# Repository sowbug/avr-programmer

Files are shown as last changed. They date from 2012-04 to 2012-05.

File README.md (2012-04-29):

AVR In-System Programmer
========================

By [Mike Tsao](http://www.sowbug.com/) and [Dennis Gentry](https://github.com/dgentry)

Introduction
============

This is a new spin on the AVR ISP. It's based on the ATmega 'u2 family of AVR devices. Influences while designing, in no particular order:

  * Adafruit's [USBtinyISP](http://www.ladyada.net/make/usbtinyisp/), based on [the original USBtiny project](http://dicks.home.xs4all.nl/avr/usbtiny/). In particular, the buffer came from this project.
  * Fabio Baltieri's [USB Key AVR Programmer](http://fabiobaltieri.com/2011/09/02/usb-key-avr-programmer/). Some early schematic ideas came from here.
  * [Saleae Logic](http://www.saleae.com/logic). Yes, I know that's not an AVR programmer, but I like their design sensibilities.
  * [Frank Zhao](http://frank-zhao.com/) provided feedback on an early version of the circuit.

Design Goals
============

  1. It should be pocketable, or capable of being kept in a mesh backpack compartment, without snagging on anything. This means SMD rather than through-hole, few or no required pin headers, and right-angle headers where headers are required.
  1. No special cables needed. In the common case of a standard 6-pin ISP header on the target board, the programmer needs only a commodity mini-B USB cable. The target audience is DIY people who are designing their own circuits, and in that case it's very unlikely new designs would use a 10-pin ISP header with 4 NC pins.
  1. It should be a real USB device rather than emulating serial over USB, so it needs fewer avrdude options to pass in.
  1. Jumpers should be truly optional. The device should be usable without jumper header pins even soldered onto the board.
  1. Support in current versions of avrdude. With the real-USB-device requirement, this narrows it down to USBasp, USBtiny, or AVRISP mkII emulation.
  1. Inexpensive. To be clear, most AVR programmers are inexpensive, and it's not a goal to be less expensive than them.
  1. Distinctive. The angled 6-pin socket satisfies this goal.
  1. Fast. This should be entirely dependent on the quality of the firmware, because the device itself should be capable of high-speed USB.
  1. Good-looking enough to be presentable without a case.
  1. JTAG/XSVF programming via [The JTAG Whisperer](https://github.com/sowbug/JTAGWhisperer). This means we need to support varying target voltages.
  1. Bring out the serial pins on the ATmega to provide a USB-to-TTL converter with an FTDI-cable-compatible pinout.
  1. Support for all low-voltage programming methods (SPI, TPI, PDI). Note that TPI/PDI turned out to be hard to do with the serial functionality. It should work, but with external resistors and a breadboard.

Notes That Will Someday Become Documentation
============================================

* Fuses are **-U lfuse:w:0xDE:m -U hfuse:w:0xD9:m -U efuse:w:0xF7:m -U lock:w:0xFF:m**. These are default with 16MHz crystal and HWBE=0.

FAQ
===

  * **Err, USBasp? USBtiny? You know those bitbang USB, right? Why consider those protocols if your ATmegaXXu2 has native USB?** It's just a question of avrdude support. Both those protocols are based on open-source hardware, so I'd prefer to base my work on them. Another consideration is that there shouldn't be a problem with borrowing their VID/PID pairs. The bit-banging aspect of the protocols is orthogonal to their suitability.
  * **Your circuit mentions the ATmega8u2. You know the '32u2 is only like $1.00 more, right?** True (actually only 40 cents more in quantity), and the initial prototypes will use the '32u2. But we're going to try to fit the intended functionality into 8KB flash and 512 bytes SRAM. Beyond that, the device is looking more like a general-purpose gadget. If we were building such a thing, the ATmega32u4 (not the 32u2) is a better choice.
  * **About that general-purpose gadget: why aren't you building one? The [Bus Pirate](http://dangerousprototypes.com/docs/Bus_Pirate) is cool.** Yes, the Bus Pirate is cool, and indeed it would be nice to have one built on an open toolchain. But this isn't that device. The intent is to have a specialized tool that's always available, never needing a misplaced cable, never needing a firmware update, during those times when you've bricked an AVR or CPLD and just need it fixed.
  * **What's this about AVRISP mkII?** Right, at the moment the prototypes are running the [LUFA project AVRISP mkII](http://www.fourwalledcubicle.com/AVRISP.php). This hardware doesn't include any of its own software, but just in case you build a copy and run LUFA on it, we'd like to incorporate [LUFA's MIT-style license](https://github.com/sowbug/lufa-lib/blob/master/trunk/LUFA/License.txt) and [copyright notice](https://github.com/sowbug/lufa-lib/blob/master/trunk/LUFA/Version.h) by reference here. Thanks, Dean!

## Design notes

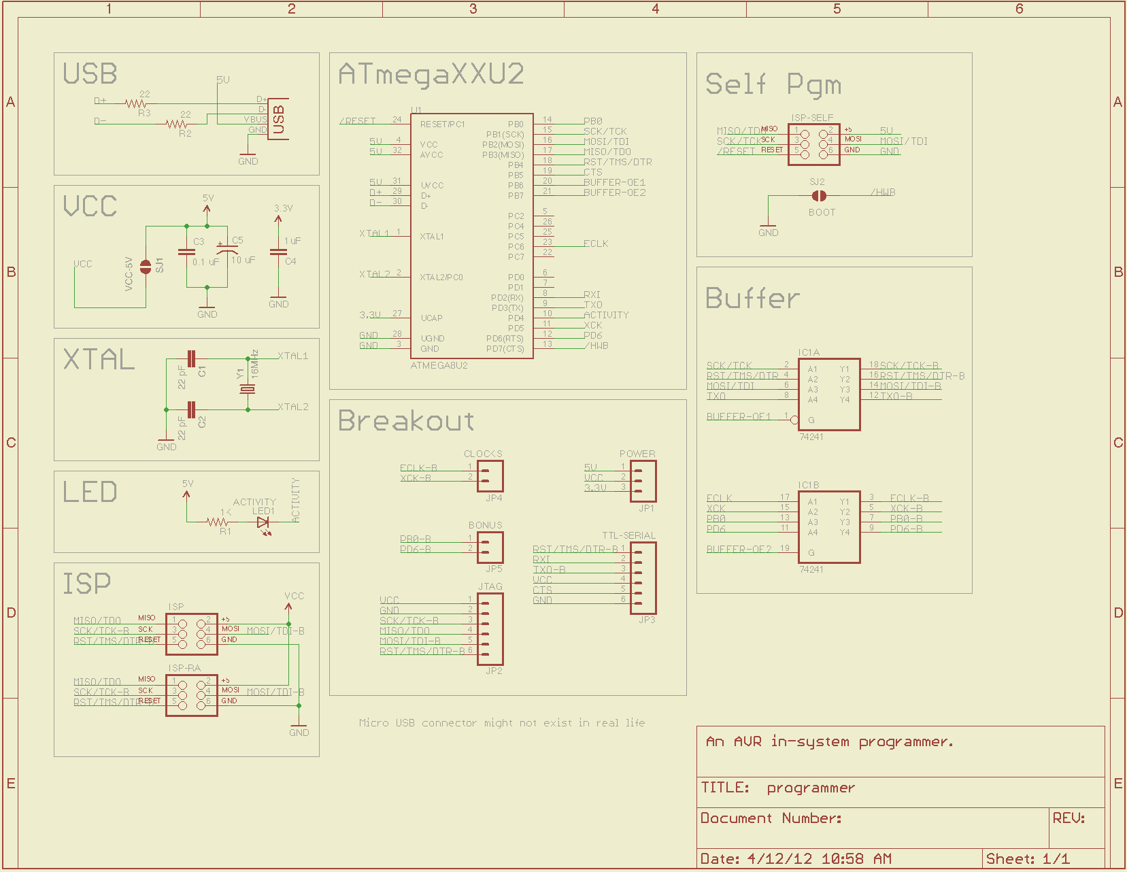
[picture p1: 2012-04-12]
programmer.sch.png

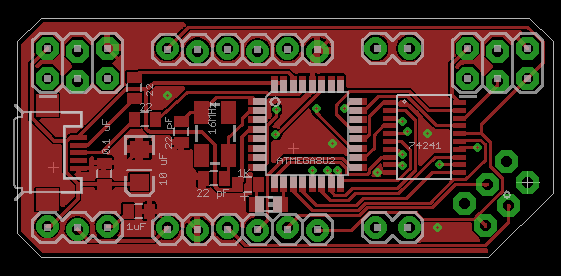
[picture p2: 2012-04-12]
programmer.brd.png

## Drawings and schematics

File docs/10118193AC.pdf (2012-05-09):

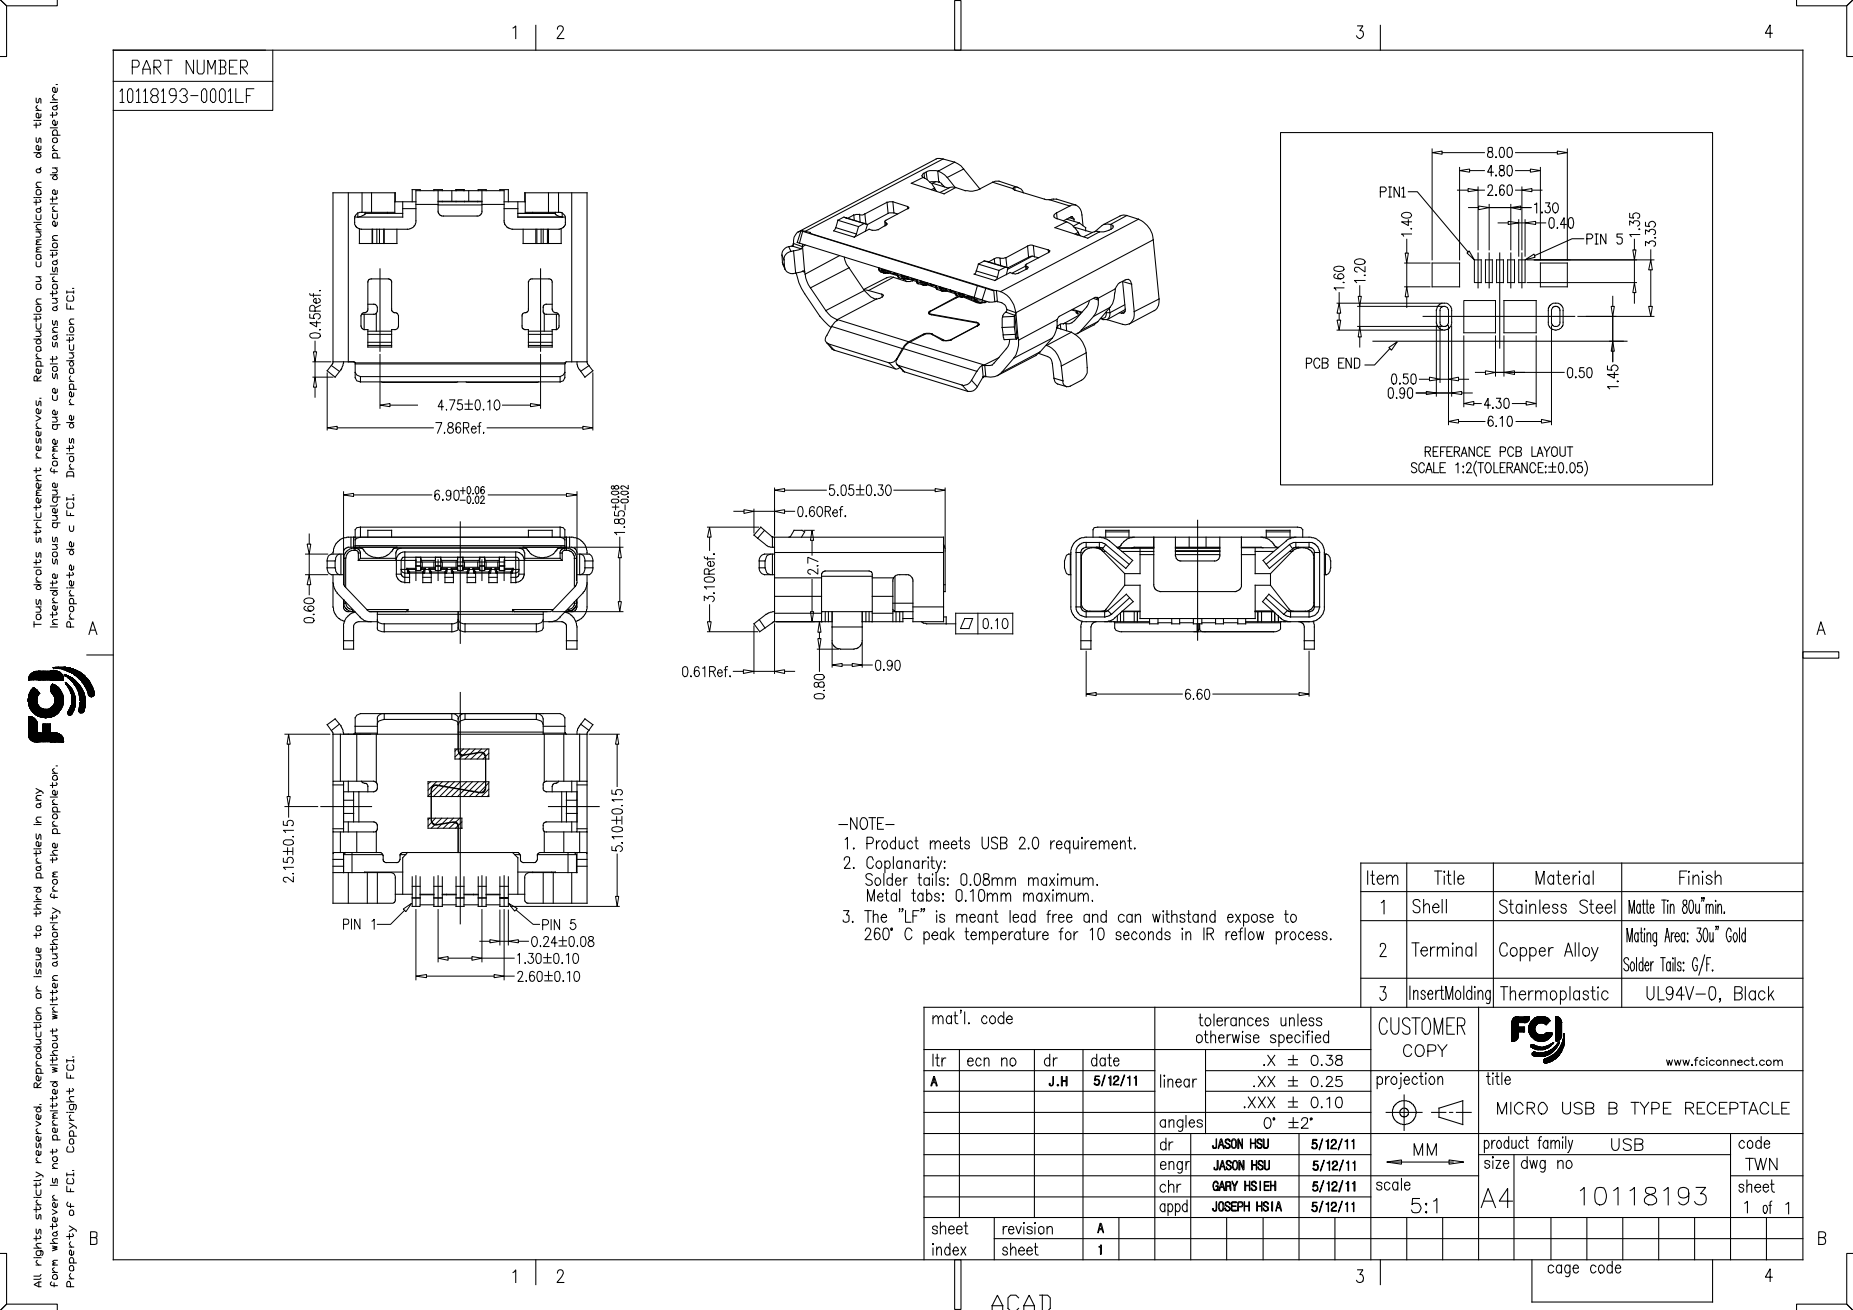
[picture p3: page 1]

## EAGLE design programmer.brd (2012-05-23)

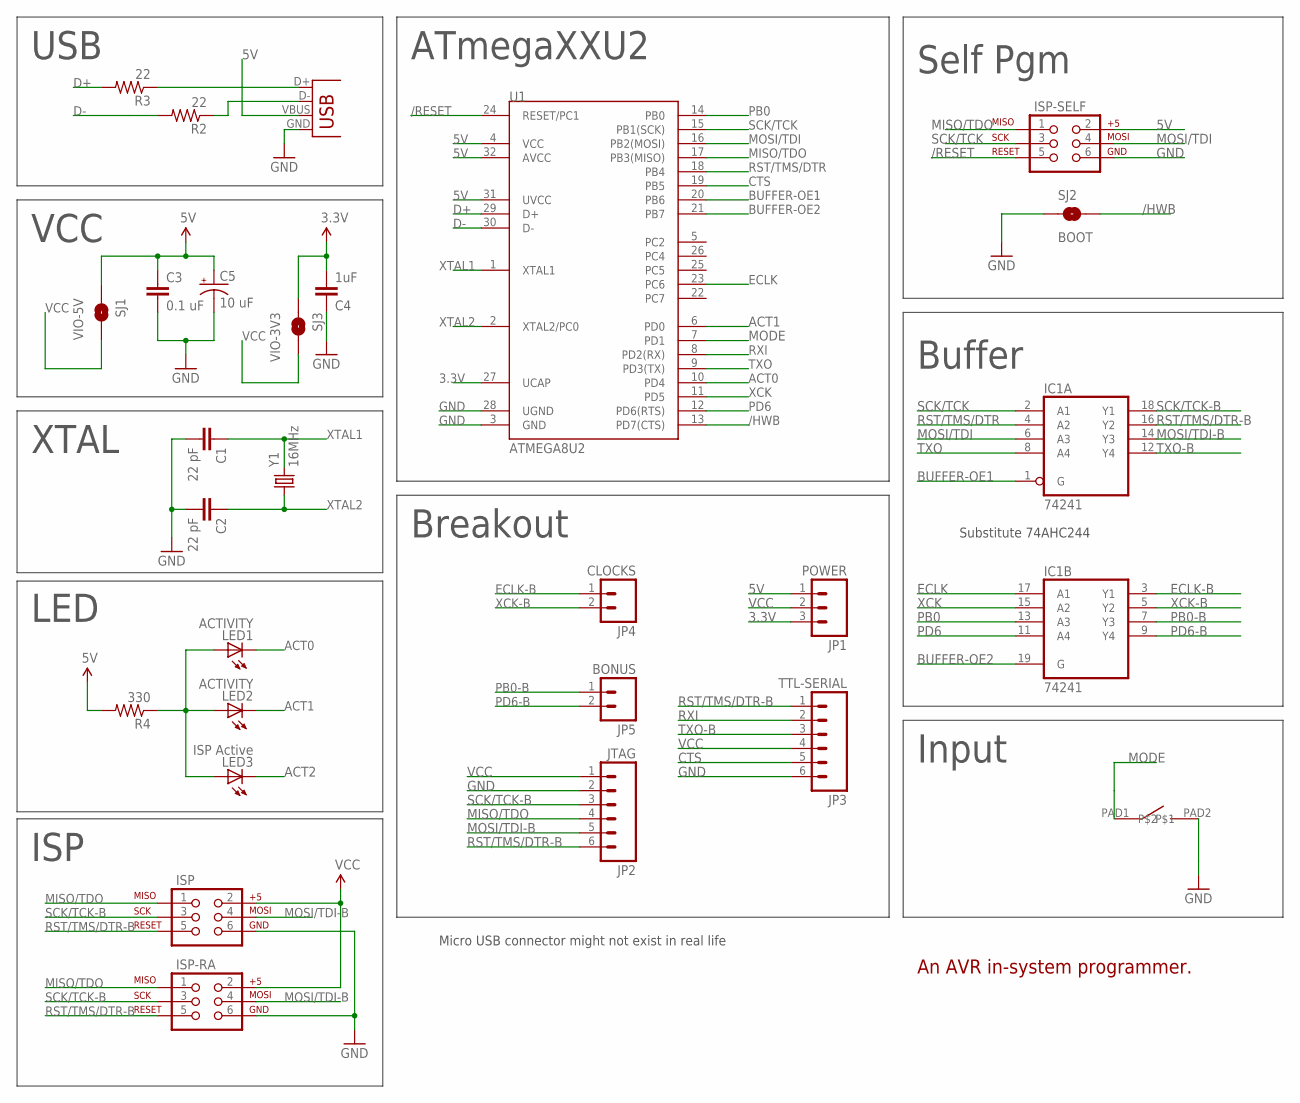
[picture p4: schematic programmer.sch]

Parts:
C1, C2: 22 pF; SPARKFUN_0805
C3: 0.1 uF; SPARKFUN_0805
C4: 1uF; SPARKFUN_0805
C5: 10 uF; SPARKFUN_EIA3216
IC1: 74241; TSSOP20
ISP: SPARKFUN_AVR_SPI_PRG_62X3_LOCK; SPARKFUN_2X3_LOCK
ISP-RA: SPARKFUN_AVR_SPI_PRG_62X3_LOCK; SPARKFUN_2X3_LOCK
ISP-SELF: SPARKFUN_AVR_SPI_PRG_62X3_LOCK; SPARKFUN_2X3_LOCK
JP1: POWER; SPARKFUN_1X03_LOCK
JP2: JTAG; SPARKFUN_1X06_LOCK
JP3: TTL-SERIAL; SPARKFUN_1X06_LOCK
JP4: CLOCKS; 1X02_LOCK
JP5: BONUS; 1X02_LOCK
LED1, LED2: ACTIVITY; CHIP-LED0805
LED3: ISP Active; CHIP-LED0805
R2, R3: 22; SPARKFUN_0805
R4: 330; SPARKFUN_0805
SJ1: VIO-5V; SPARKFUN_SJ_2S
SJ2: BOOT; SPARKFUN_SJ_2S-NO
SJ3: VIO-3V3; SPARKFUN_SJ_2S
SW1: BUTTON_TD-85XU
U1: ATMEGA8U2; SPARKFUN_TQFP32-08
X1: FCI_8193_MICRO_USB; FCI_MICRO_USB_8193
Y1: 16MHz; SPARKFUN_CRYSTAL-SMD-5X3

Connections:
3.3V: C4.2, JP1.3, SJ3.1, U1.27 (UCAP)
5V: C3.1, C5.A (+), ISP-SELF.2, JP1.1, R4.2, SJ1.1, U1.4 (VCC), U1.31 (UVCC), U1.32 (AVCC), X1.VBUS
/HWB: SJ2.2, U1.13 (PD7(CTS))
/RESET: ISP-SELF.5, U1.24 (RESET/PC1)
ACT0: LED1.C, U1.10 (PD4)
ACT1: LED2.C, U1.6 (PD0)
ACT2: LED3.C
BUFFER-OE1: IC1.1 (G), U1.20 (PB6)
BUFFER-OE2: IC1.19 (G), U1.21 (PB7)
CTS: JP3.5, U1.19 (PB5)
D+: R3.2, U1.29 (D+)
D+RAW: R3.1, X1.D+
D-: R2.2, U1.30 (D-)
D-RAW: R2.1, X1.D-
ECLK: IC1.17 (A1), U1.23 (PC6)
ECLK-B: IC1.3 (Y1), JP4.1
GND: C1.2, C2.2, C3.2, C4.1, C5.C (-), IC1.10 (GND), ISP.6, ISP-RA.6, ISP-SELF.6, JP2.2, JP3.6, SJ2.1, SW1.PAD2, U1.3 (GND), U1.28 (UGND), X1.GND
MISO/TDO: ISP.1, ISP-RA.1, ISP-SELF.1, JP2.4, U1.17 (PB3(MISO))
MODE: SW1.PAD1, U1.7 (PD1)
MOSI/TDI: IC1.6 (A3), ISP-SELF.4, U1.16 (PB2(MOSI))
MOSI/TDI-B: IC1.14 (Y3), ISP.4, ISP-RA.4, JP2.5
PB0: IC1.13 (A3), U1.14 (PB0)
PB0-B: IC1.7 (Y3), JP5.1
PD6: IC1.11 (A4), U1.12 (PD6(RTS))
PD6-B: IC1.9 (Y4), JP5.2
RST/TMS/DTR: IC1.4 (A2), U1.18 (PB4)
RST/TMS/DTR-B: IC1.16 (Y2), ISP.5, ISP-RA.5, JP2.6, JP3.1
RXI: JP3.2, U1.8 (PD2(RX))
SCK/TCK: IC1.2 (A1), ISP-SELF.3, U1.15 (PB1(SCK))
SCK/TCK-B: IC1.18 (Y1), ISP.3, ISP-RA.3, JP2.3
TXO: IC1.8 (A4), U1.9 (PD3(TX))
TXO-B: IC1.12 (Y4), JP3.3
VCC: IC1.20 (VCC), ISP.2, ISP-RA.2, JP1.2, JP2.1, JP3.4, SJ1.2, SJ3.2
VCC-LED: LED1.A, LED2.A, R4.1
VCC-LED1: LED3.A
XCK: IC1.15 (A2), U1.11 (PD5)
XCK-B: IC1.5 (Y2), JP4.2
XTAL1: C1.1, U1.1 (XTAL1), Y1.3 (2)
XTAL2: C2.1, U1.2 (XTAL2/PC0), Y1.1

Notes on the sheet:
USB
ISP
Self Pgm
VCC
XTAL
LED
An AVR in-system programmer.
Buffer
Breakout
ATmegaXXU2
Micro USB connector might not exist in real life
Substitute 74AHC244
Input

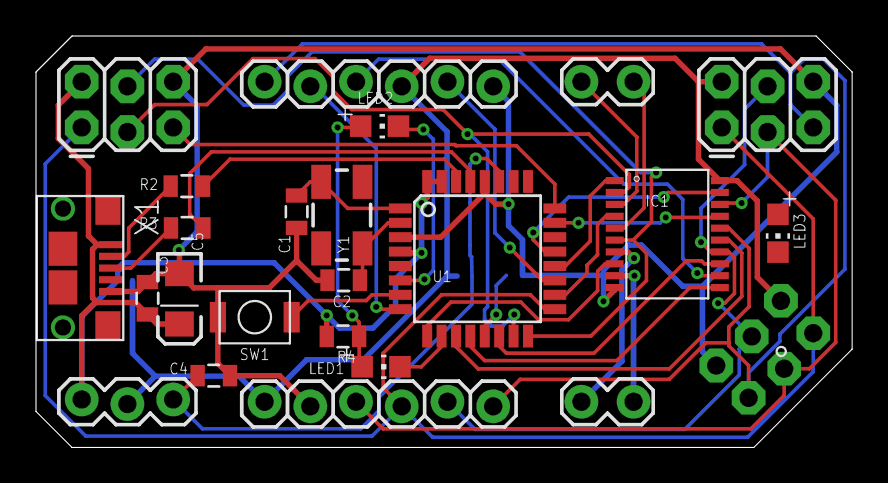
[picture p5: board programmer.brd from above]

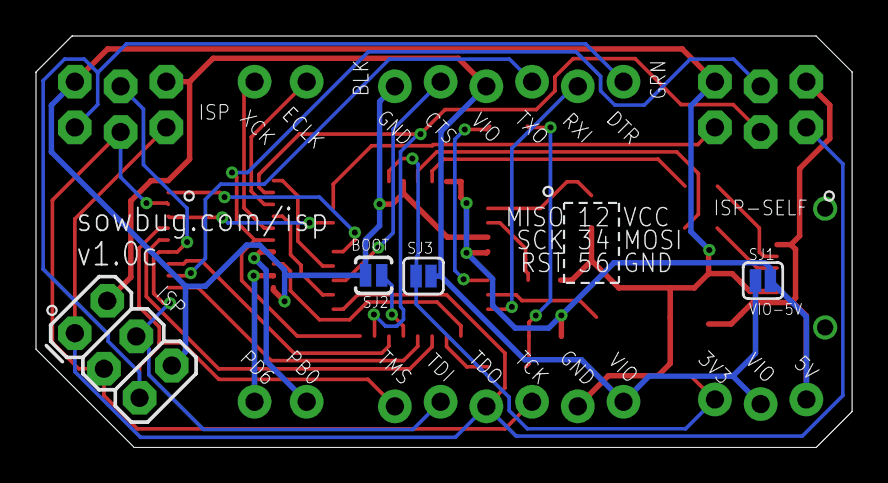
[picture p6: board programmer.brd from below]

Board: 2 copper layers, 45.3 x 22.9 mm, 27 parts (4 on the bottom side), 37 nets.

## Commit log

2012-02-25 New. Notched design.
    [programmer.brd, programmer.sch]
2012-02-25 Angled 6-pin ISP.
    [programmer.brd, programmer.sch]
2012-02-25 More work on layout. SJ1. Polarized 10uF cap. Fixed ISP2 orientation.
    [programmer.brd, programmer.sch]
2012-02-25 Generated schematic image.
2012-02-25 Wider. Added SJ1 connection.
    [programmer.brd]
2012-02-25 Better routing setup. Moved SJ1 jumper temporarily.
    [programmer.brd, programmer.sch]
2012-02-25 Nudge here and there to get rid of DRC errors.
    [programmer.brd]
2012-02-26 Fixed error in self-program jumper. Balanced components.
    [programmer.brd, programmer.sch]
2012-02-26 Removed BUFF-OE.
    [programmer.brd, programmer.sch]
2012-02-26 Added buffer and JTAG/voltage pinouts.
    [programmer.brd, programmer.sch]
2012-02-26 Fixed '125 name on board.
    [programmer.brd, programmer.sch]
2012-02-26 Named all netlists. More consistent lettering.
    [programmer.brd, programmer.sch]
2012-02-26 Pour ground planes.
    [programmer.brd, programmer.sch]
2012-02-27 Fixed resistor numbering. Moved SJ1 jumper off board. Won't autoroute.
    [programmer.brd, programmer.sch]
2012-02-27 Got it to route by adding polygons afterward.
    [programmer.brd, programmer.sch]
2012-02-27 VCC is now independent of uC supply. Thx Frank Zhao!
    [programmer.brd, programmer.sch]
2012-02-28 Smaller, fewer vias
    [programmer.brd, programmer.sch]
2012-02-28 Resolved conflicts with dgentry's optimizations.
    [programmer.brd, programmer.sch]
2012-02-28 Ground planes.
    [programmer.brd]
2012-02-28 Fixed: PB0 replaced with RST for JTAG header.
    [programmer.brd, programmer.sch]
2012-02-28 Fixed miswired RESET/RST/RST-UC.
    [programmer.brd, programmer.sch]
2012-03-03 v1.0.1, 1 via
    [programmer.brd]
2012-03-03 v1.0s. s for squished
    [programmer.brd]
2012-03-03 Moved ISP6 dot. Removed floating jumper connector.
    [programmer.brd]
2012-03-03 Improved power and GND polygons, moved sowbug.com to a place where it won't get drilled
    [programmer.brd]
2012-03-03 Beefed up GND on bottom layer; cleaned up messy thermal/routing interaction near uC power
    [programmer.brd]
2012-03-20 Made labels bigger, where possible.
    [programmer.brd]
2012-03-25 Everything is messed up.
    [programmer.brd, programmer.sch]
2012-03-26 Rearranged a bit, routed. 9 vias. Could do better with some pinswapping.
    [programmer.brd]
2012-04-01 Fixed labels. Nothing is obscured.
    [programmer.brd, programmer.sch]
2012-04-01 Removed unnecessary pullups. Moved bottom labels to right layer.
    [programmer.brd, programmer.sch]
2012-04-01 Ground planes were nothing planes. Fixed.
    [programmer.brd]
2012-04-01 Moved all parts to local lbr. IC2->IC1.
    [programmer.brd, programmer.sch]
2012-04-01 Renamed to match version number on silkscreen.
2012-04-03 Re-route to 24 vias.
    [programmer.brd, programmer.sch]
2012-04-03 Added ground planes and some ground vias
    [programmer.brd]
2012-04-03 Got rid of obsolete .pngs. Also, this routing uses fat power and ground.
2012-04-03 Pass design rules and write a .png
    [programmer.brd]
2012-04-03 Shrunk a bit.
    [programmer.brd]
2012-04-03 Nudged vias off bottom silk text.
    [programmer.brd]
2012-04-04 Aligned labels. Isolated 6-pin JTAG and TTL-serial headers.
    [programmer.brd]
2012-04-04 An unknown change after pouring the ground planes.
    [programmer.brd]
2012-04-04 Added gratuitous ground plane vias for more complete coverage. There was already one (routing, not ground plane) via in a slightly bottom silk-obscuring place, but this change doesn't add any more.
    [programmer.brd]
2012-04-04 Passes design rules now. More gratuitous ground plane vias, none of which obscure silk.
    [programmer.brd]
2012-04-11 8 mil traces and vias = cheaper fab
    [programmer.brd, programmer.sch]
2012-04-12 8 mil, reasonable routing.
    [programmer.brd]
2012-04-12 8 mil traces, 14 vias, beveled corners
    [programmer.brd]
2012-04-12 Add note about substituting '244.
    [programmer.sch]
2012-04-12 DP's auto-generated BOM, in inconvenient HTML format\!
2012-04-24 Documentation about fuses.
2012-04-26 Various changes.
    - Change VCC labels to VIO (https://github.com/sowbug/avr-programmer/issues/15).
    - Change LED resistor from 1K to 330 (https://github.com/sowbug/avr-programmer/issues/16).
    - Added second status LED (https://github.com/sowbug/avr-programmer/issues/9).
    [programmer.brd, programmer.sch]
2012-04-26 Add SJ3 for 3V3 -> VIO.
    [programmer.brd, programmer.sch]
2012-04-27 Added switch.
    [programmer.brd, programmer.sch]
2012-04-28 Add FCI 10118193 USB socket.
    [programmer.brd, programmer.sch]
2012-04-28 Adjust pads.
    [programmer.brd, programmer.sch]
2012-04-28 Switched drill to via, so we get a bit of solder mask around the pegs.
    [programmer.brd, programmer.sch]
2012-04-28 Switch to funky TD-85XU button.
    [programmer.brd, programmer.sch]
2012-05-23 3 Activity LEDs. One might not be hooked up yet, though.
    [programmer.brd, programmer.sch]

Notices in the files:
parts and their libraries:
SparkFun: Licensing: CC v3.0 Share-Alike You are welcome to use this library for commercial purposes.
